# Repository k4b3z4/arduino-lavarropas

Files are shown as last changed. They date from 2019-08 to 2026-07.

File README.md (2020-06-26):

# arduino-lavarropas
 replacement of mechanical washing machine programmer with arduino uno

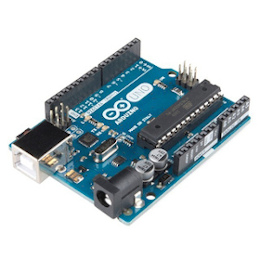
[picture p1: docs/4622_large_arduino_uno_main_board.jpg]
arduino

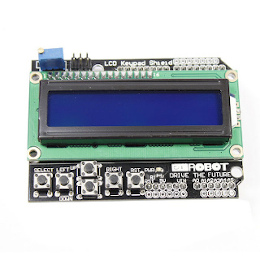
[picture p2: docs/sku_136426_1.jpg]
display shield

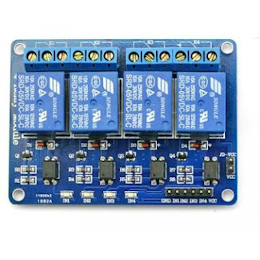
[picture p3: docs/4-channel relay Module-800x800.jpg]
relay module


# Esquema Electrico:

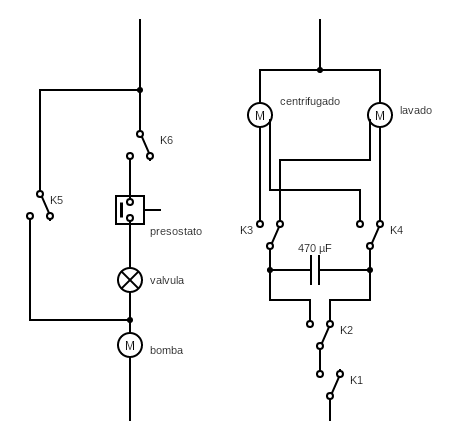
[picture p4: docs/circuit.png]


# Cableado Electrico:

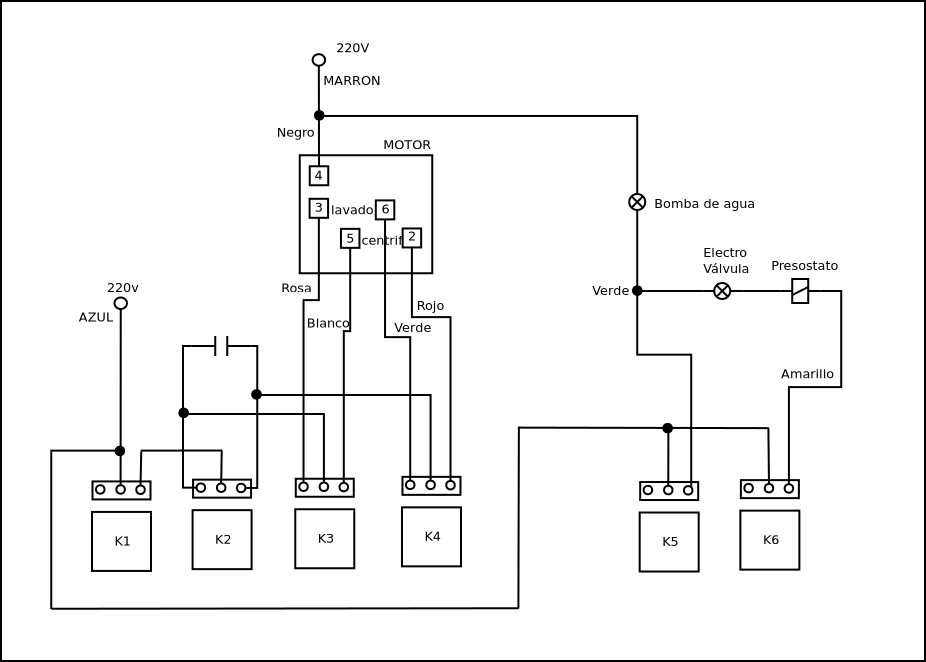
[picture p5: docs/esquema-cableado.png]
cableado


# Manual Orignal completo PDF

manual

# Funciona:

* Programa largo B -> C -> D -> E
* Programa corto K
* carga de agua
* bomba de vaciado 
* Presostato para limitar nivel de carga

# No Funciona:

* falta cableado bloqueador de apertura
* falta cableado calefactor y termostato
* falta selector de ingreso de agua, el sistema es mecánico (siempre está en posicion enjuague, no es un problema si se utiliza jabón liquido) 
* falta cableado boton "no centrifuga"
* falta cableado boton "no desagota"

# Archivos 3D:

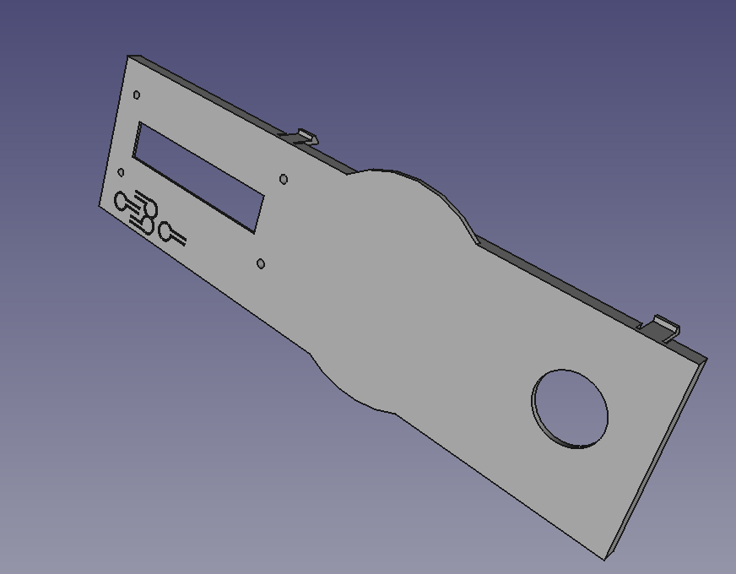
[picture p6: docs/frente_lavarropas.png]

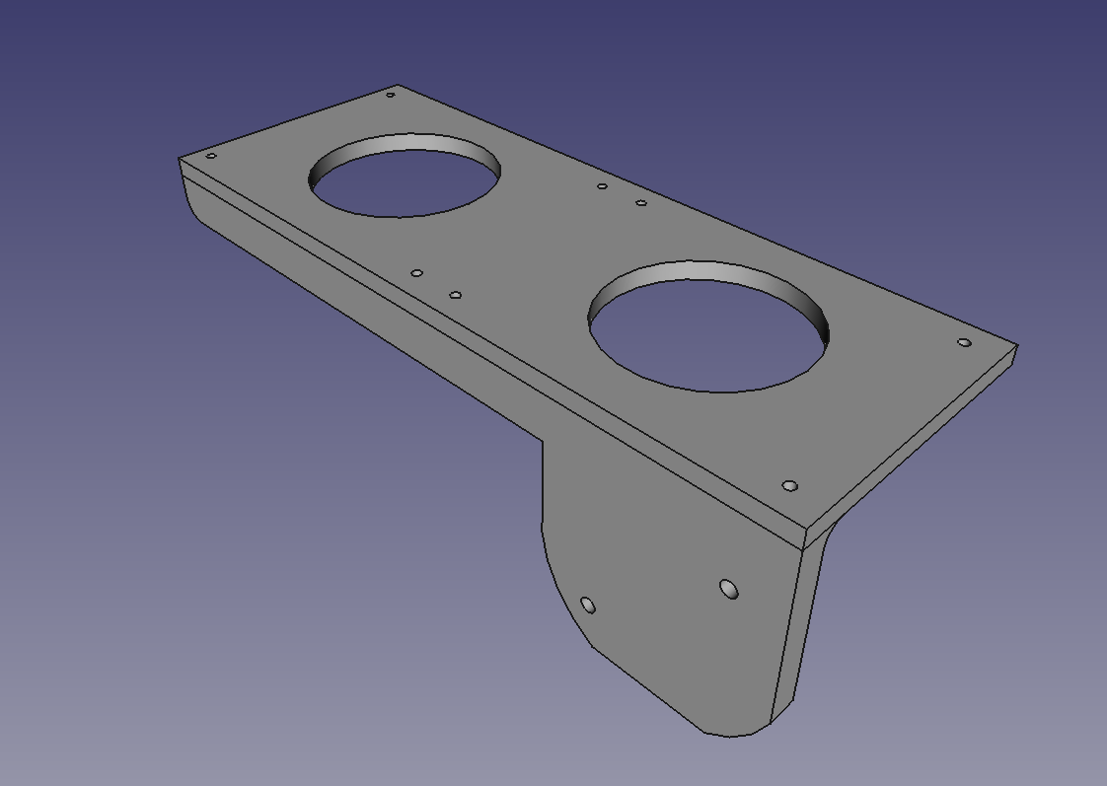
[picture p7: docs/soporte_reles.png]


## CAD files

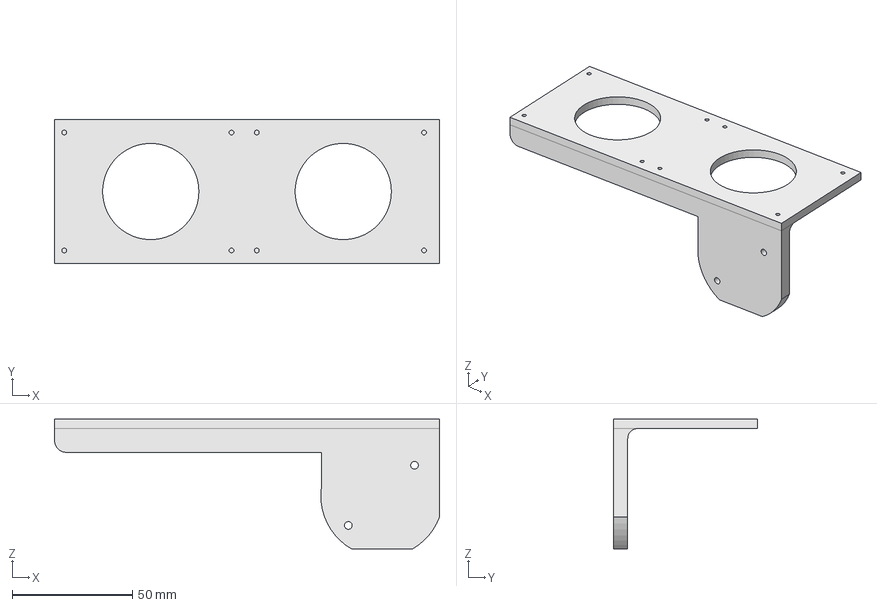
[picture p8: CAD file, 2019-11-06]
3D_files/soporte_lavarropas.FCStd
160.0 x 60.0 x 54.0 mm

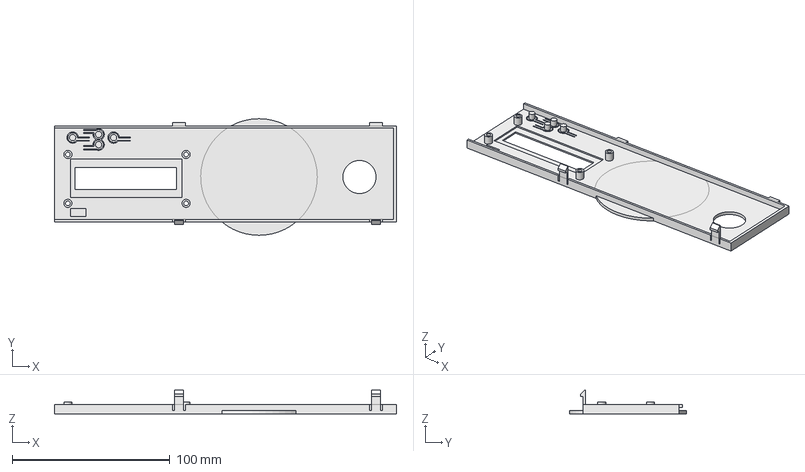
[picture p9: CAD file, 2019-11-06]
3D_files/frente_lavarropas.FCStd
217.0 x 74.0 x 15.0 mm

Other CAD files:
3D_files/frente_lavarropas.amf
3D_files/soporte_lavarropas.amf

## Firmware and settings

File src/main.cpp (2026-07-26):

// ********************************************************************
// Automatizacion Lavarropas
// Arduino Uno + LCD + encoder
// Federico Pedot fedped@gmail.com
//
// ********************************************************************

#include <Arduino.h>
#include <Wire.h>
#include <Timer.h>
#include <LiquidCrystal.h>
#include "programas.h"
#include <EEPROM.h>
#include "EEPROMAnything.h"



// ********************************************************************
// Config Shield

// LCD
#define PIN_RS A0
#define PIN_E  A1
#define PIN_D4 A2
#define PIN_D5 A3
#define PIN_D6 A4
#define PIN_D7 A5
#define PIN_CT 6

// DIGITAL
#define PIN_K1 8
#define PIN_K2 9
#define PIN_K3 10
#define PIN_K4 11
#define PIN_K5 12
#define PIN_K6 13


// ENCODER
#define PIN_CLK  2
#define PIN_DATA 3
#define PIN_SW   4

// BEEP
#define PIN_BEEP 7

// *******************************************************************

Timer timer2; // timer para Reloj
Timer timer3; // timer para beep

LiquidCrystal lcd(PIN_RS, PIN_E, PIN_D4, PIN_D5, PIN_D6, PIN_D7);


int    contador  = 0;
int    incrementa_contador = 0;
int    segundos  = 0;
bool   lavando   = false;
int    programa  = 1;
bool   cambia_programa = false;
int    boton     = 0;
char   buffer[18];

int  menu_posicion = 0;
int  menu_activar  = 0;
bool menu_presionado = false;
bool menu_parar = false;
bool menu_pausa = false;


int  encoder_val = 0;
int  encoder = 0;
int  state;


int beeps = 0;

// *******************************************************************

void IncrementaContador(void);
void Reloj(void);
void Beep(void);
void Estado(byte);
void doEncoder(void);
int  calculaTotal(int);

// *******************************************************************



void setup() {

    // contactores
    pinMode(PIN_K1, OUTPUT);
    pinMode(PIN_K2, OUTPUT);
    pinMode(PIN_K3, OUTPUT);
    pinMode(PIN_K4, OUTPUT);
    pinMode(PIN_K5, OUTPUT);
    pinMode(PIN_K6, OUTPUT);

    digitalWrite(PIN_K1, 1);
    digitalWrite(PIN_K2, 1);
    digitalWrite(PIN_K3, 1);
    digitalWrite(PIN_K4, 1);
    digitalWrite(PIN_K5, 1);
    digitalWrite(PIN_K6, 1);

    // encoder
    pinMode(PIN_SW, INPUT_PULLUP);
    pinMode(PIN_DATA, INPUT_PULLUP);
    pinMode(PIN_CLK, INPUT_PULLUP);
    
    // beep
    pinMode(PIN_BEEP, OUTPUT);
    digitalWrite(PIN_BEEP, 0);

    // contraste LCD
    pinMode(PIN_CT, OUTPUT);
    analogWrite(PIN_CT, 96);

    // 1 segundo
    timer2.every(1000, Reloj);

    // 200 ms
    timer3.every(200, Beep);

    // set up the LCD's number of columns and rows:
    lcd.begin(16, 2);

    // Primer programa
    cambia_programa = true;

    // segunda linea
    lcd.setCursor(0, 1);
    lcd.print("Listo...        ");


    // interrupcion encoder
    attachInterrupt(digitalPinToInterrupt(PIN_CLK), doEncoder, CHANGE);
    attachInterrupt(digitalPinToInterrupt(PIN_DATA), doEncoder, CHANGE);


    //recupera valores de la EEPROM
    EEPROM_readAnything(10, lavando);
    
    if(lavando){
        EEPROM_readAnything(20, programa);
        EEPROM_readAnything(30, segundos);
        EEPROM_readAnything(40, contador);
        cambia_programa = false;
        lcd.setCursor(0, 0);
        lcd.print("Recup");
        beeps = 2;
    }else{
        beeps = 3;
    }

}


// ###########################################################################
// ######################## Loop Principal ###################################

void loop() {

    // Menu seleccion de programa
    if (menu_posicion == 1 && lavando == false){

        lcd.setCursor(0,1);

        switch (encoder_val){
            case 1:
                lcd.print("[B]CDE-K-L-V-X-");
                break;
            case 2:
                lcd.print("B[C]DE-K-L-V-X-");
                break;
            case 3:
                lcd.print("BC[D]E-K-L-V-X-");
                break;
            case 4:
                lcd.print("BCD[E]-K-L-V-X-");
                break;
            case 5:
                lcd.print("BCDE[-]K-L-V-X-");
                break;
            case 6:
                lcd.print("BCDE-[K]-L-V-X-");
                break;
            case 7:
                lcd.print("BCDE-K[-]L-V-X-");
                break;
            case 8:
                lcd.print("BCDE-K-[L]-V-X-");
                break;
            case 9:
                lcd.print("BCDE-K-L[-]V-X-");
                break;
            case 10:
                lcd.print("BCDE-K-L-[V]-X-");
                break;
            case 11:
                lcd.print("BCDE-K-L-V[-]X-");
                break;
            case 12:
                lcd.print("BCDE-K-L-V-[X]-");
                break;
            case 13:
                lcd.print("BCDE-K-L-V-X[-]");
                break;
        }

        segundos = calculaTotal(encoder_val);

        if (encoder > 56) encoder = 56;
        if (encoder < 1)  encoder = 1; 
        

    }

    // Menu detener lavado (modo pausa)
    if( menu_posicion == 1 && lavando == true){

        if (encoder_val == 0){
            lcd.setCursor(0,1);       
            lcd.print("Parar? [No] Si ");
            menu_parar = false;
        }
        if (encoder_val == 1){ 
            lcd.setCursor(0,1);
            lcd.print("Parar?  No [Si]");
            menu_parar = true;
        }
        if (encoder > 7) encoder = 7;
        if (encoder < 0) encoder = 0;

    }


    // click Menu
    if( !digitalRead(PIN_SW) & !menu_presionado){

        menu_presionado = 1;
        encoder = 0;

        // activa menu principal
        if(menu_posicion == 0){
            encoder_val = 1;
            if (lavando == false){
                lcd.clear();
                lcd.setCursor(0,0);  
                lcd.print("Prg?");
                menu_posicion = 1;
            }else{
                menu_posicion = 1;
                menu_pausa = true;
                digitalWrite(PIN_K1, 1);
                digitalWrite(PIN_K2, 1);
                digitalWrite(PIN_K3, 1);
                digitalWrite(PIN_K4, 1);
                digitalWrite(PIN_K5, 1);
                digitalWrite(PIN_K6, 1);
            }
        }

        // vuelve del menu principal
        else if(menu_posicion == 1){
            if(lavando == false){ 
                // si no estaba lavando cambia al programa seleccionado
                // y comienza el ciclo de lavado 'lavando=true'
                programa = encoder_val;
                EEPROM_writeAnything(20, programa);
                lcd.setCursor(0,1);
                lcd.print("               ");
                if(programa == 1 || programa == 2 || 
                   programa == 3 || programa == 4 || 
                   programa == 6 || programa == 8 ||
                   programa == 10 || programa == 12 ){
                    lavando = true;
                    EEPROM_writeAnything(10, lavando);
                }
                cambia_programa = true;
            }else{
                // si estaba lavando y decido parar => lavando=false
                // si no quiero detener, todo sigue igual Continuando...
                if(menu_parar){
                    lavando = false;
                    EEPROM_writeAnything(10, lavando);
                    lcd.setCursor(0, 0);
                    lcd.print("Prog -  00:00:00");
                    lcd.setCursor(0, 1);
                    lcd.print("Finalizado      ");
                }else{
                    lcd.setCursor(0,1);
                    lcd.print("Continuando...  ");
                }
                menu_pausa = false;
            }
            menu_posicion = 0;
        }

    }

    if(digitalRead(PIN_SW)){
        menu_presionado = 0;
    }

    if(cambia_programa){

        lcd.setCursor(0, 0);

        switch (programa){
            case 1:
                lcd.print("Prg B");
                break;
            case 2:
                lcd.print("Prg C");
                break;
            case 3:
                lcd.print("Prg D");
                break;
            case 4:
                lcd.print("Prg E");
                break;
            case 6:
                lcd.print("Prg K");
                break;
            case 8:
                lcd.print("Prg L");
                break;
            case 10:
                lcd.print("Prg V");
                break;
            case 12:
                lcd.print("Prg X");
                break;
            case 5:
            case 7:
            case 9:
            case 11:
            case 13:
                lcd.print("Prg -");
                digitalWrite(PIN_K1, 1);
                digitalWrite(PIN_K2, 1);
                digitalWrite(PIN_K3, 1);
                digitalWrite(PIN_K4, 1);
                digitalWrite(PIN_K5, 1);
                digitalWrite(PIN_K6, 1);
                lavando = false;
                EEPROM_writeAnything(10, lavando);
                break;
        }

        segundos = calculaTotal(programa);
        cambia_programa = false;

    }

    timer2.update();
    timer3.update();

}

// ###########################################################################
// ###########################################################################


void Reloj(){

    int h;
    int m;
    int s;


    if(lavando == true and menu_pausa == false){
        segundos--;
        incrementa_contador++;
        if(incrementa_contador > 9){
            incrementa_contador = 0;
            IncrementaContador();
            EEPROM_writeAnything(30, segundos);
        }
    }


    h = segundos / 3600;
    m = ( segundos % 3600 ) / 60;
    s = ( segundos % 3600 ) % 60;

    lcd.setCursor(8, 0);
    sprintf(buffer,"%02d:%02d:%02d",h,m,s);
    lcd.print(buffer);


    return;
}

void Beep(void){

    if (beeps > 0){
        if(digitalRead(PIN_BEEP)){
            digitalWrite(PIN_BEEP,0);
            beeps--;
        }else{
            digitalWrite(PIN_BEEP,1);
        }
    }


}

// ###########################################################################
// ###########################################################################

void IncrementaContador() {

    if(programa == 1){
        digitalWrite(PIN_K1, !(PROG_B[contador] & B10000000 ));
        digitalWrite(PIN_K2, !(PROG_B[contador] & B01000000 ));
        digitalWrite(PIN_K3, !(PROG_B[contador] & B00100000 ));
        digitalWrite(PIN_K4, !(PROG_B[contador] & B00010000 ));
        digitalWrite(PIN_K5, !(PROG_B[contador] & B00001000 ));
        digitalWrite(PIN_K6, !(PROG_B[contador] & B00000100 ));
        if(PROG_B[contador] & B00000001) beeps = 6;
        Estado(PROG_B[contador]);
        if(contador == sizeof(PROG_B)-1 ){
            cambia_programa=true;
            programa ++;
            contador = 0;
            incrementa_contador = 0;
            EEPROM_writeAnything(20, programa);
            EEPROM_writeAnything(40, contador);
            return;
        }
    }

    if(programa == 2){
        digitalWrite(PIN_K1, !(PROG_C[contador] & B10000000 ));
        digitalWrite(PIN_K2, !(PROG_C[contador] & B01000000 ));
        digitalWrite(PIN_K3, !(PROG_C[contador] & B00100000 ));
        digitalWrite(PIN_K4, !(PROG_C[contador] & B00010000 ));
        digitalWrite(PIN_K5, !(PROG_C[contador] & B00001000 ));
        digitalWrite(PIN_K6, !(PROG_C[contador] & B00000100 ));
        if(PROG_C[contador] & B00000001) beeps = 6;
        Estado(PROG_C[contador]);
        if(contador == sizeof(PROG_C)-1 ){
            cambia_programa=true;
            programa ++;
            contador = 0;
            incrementa_contador = 0;
            EEPROM_writeAnything(20, programa);
            EEPROM_writeAnything(40, contador);
            return;
        }
    }

    if(programa == 3){
        digitalWrite(PIN_K1, !(PROG_D[contador] & B10000000));
        digitalWrite(PIN_K2, !(PROG_D[contador] & B01000000));
        digitalWrite(PIN_K3, !(PROG_D[contador] & B00100000));
        digitalWrite(PIN_K4, !(PROG_D[contador] & B00010000));
        digitalWrite(PIN_K5, !(PROG_D[contador] & B00001000));
        digitalWrite(PIN_K6, !(PROG_D[contador] & B00000100));
        if(PROG_D[contador] & B00000001) beeps = 6;
        Estado(PROG_D[contador]);
        if(contador == sizeof(PROG_D)-1 ){
            cambia_programa=true;
            programa ++;
            contador = 0;
            incrementa_contador = 0;
            EEPROM_writeAnything(20, programa);
            EEPROM_writeAnything(40, contador);
            return;
        }
    }

    if(programa == 4){
        digitalWrite(PIN_K1, !(PROG_E[contador] & B10000000));
        digitalWrite(PIN_K2, !(PROG_E[contador] & B01000000));
        digitalWrite(PIN_K3, !(PROG_E[contador] & B00100000));
        digitalWrite(PIN_K4, !(PROG_E[contador] & B00010000));
        digitalWrite(PIN_K5, !(PROG_E[contador] & B00001000));
        digitalWrite(PIN_K6, !(PROG_E[contador] & B00000100));
        if(PROG_E[contador] & B00000001) beeps = 6;
        Estado(PROG_E[contador]);
        if(contador == sizeof(PROG_E)-1 ){
            lcd.setCursor(0, 1);
            lcd.print("Finalizado      ");
            cambia_programa=true;
            programa ++;
            contador = 0;
            incrementa_contador = 0;
            EEPROM_writeAnything(20, programa);
            EEPROM_writeAnything(40, contador);
            return;
        }
    }

    if(programa == 6){
        digitalWrite(PIN_K1, !(PROG_K[contador] & B10000000));
        digitalWrite(PIN_K2, !(PROG_K[contador] & B01000000));
        digitalWrite(PIN_K3, !(PROG_K[contador] & B00100000));
        digitalWrite(PIN_K4, !(PROG_K[contador] & B00010000));
        digitalWrite(PIN_K5, !(PROG_K[contador] & B00001000));
        digitalWrite(PIN_K6, !(PROG_K[contador] & B00000100));
        if(PROG_K[contador] & B00000001) beeps = 6;
        Estado(PROG_K[contador]);
        if(contador == sizeof(PROG_K)-1 ){
            lcd.setCursor(0, 1);
            lcd.print("Finalizado      ");
            cambia_programa=true;
            programa ++;
            contador = 0;
            incrementa_contador = 0;
            EEPROM_writeAnything(20, programa);
            EEPROM_writeAnything(40, contador);
            return;
        }
    }

    if(programa == 8){
        digitalWrite(PIN_K1, !(PROG_L[contador] & B10000000));
        digitalWrite(PIN_K2, !(PROG_L[contador] & B01000000));
        digitalWrite(PIN_K3, !(PROG_L[contador] & B00100000));
        digitalWrite(PIN_K4, !(PROG_L[contador] & B00010000));
        digitalWrite(PIN_K5, !(PROG_L[contador] & B00001000));
        digitalWrite(PIN_K6, !(PROG_L[contador] & B00000100));
        if(PROG_L[contador] & B00000001) beeps = 6;
        Estado(PROG_L[contador]);
        if(contador == sizeof(PROG_L)-1 ){
            lcd.setCursor(0, 1);
            lcd.print("Finalizado      ");
            cambia_programa=true;
            programa ++;
            contador = 0;
            incrementa_contador = 0;
            EEPROM_writeAnything(20, programa);
            EEPROM_writeAnything(40, contador);
            return;
        }
    }

    if(programa == 10){
        digitalWrite(PIN_K1, !(PROG_V[contador] & B10000000));
        digitalWrite(PIN_K2, !(PROG_V[contador] & B01000000));
        digitalWrite(PIN_K3, !(PROG_V[contador] & B00100000));
        digitalWrite(PIN_K4, !(PROG_V[contador] & B00010000));
        digitalWrite(PIN_K5, !(PROG_V[contador] & B00001000));
        digitalWrite(PIN_K6, !(PROG_V[contador] & B00000100));
        if(PROG_V[contador] & B00000001) beeps = 6;
        Estado(PROG_V[contador]);
        if(contador == sizeof(PROG_V)-1 ){
            lcd.setCursor(0, 1);
            lcd.print("Finalizado      ");
            cambia_programa=true;
            programa ++;
            contador = 0;
            incrementa_contador = 0;
            EEPROM_writeAnything(20, programa);
            EEPROM_writeAnything(40, contador);
            return;
        }
    }

    if(programa == 12){
        digitalWrite(PIN_K1, !(PROG_X[contador] & B10000000));
        digitalWrite(PIN_K2, !(PROG_X[contador] & B01000000));
        digitalWrite(PIN_K3, !(PROG_X[contador] & B00100000));
        digitalWrite(PIN_K4, !(PROG_X[contador] & B00010000));
        digitalWrite(PIN_K5, !(PROG_X[contador] & B00001000));
        digitalWrite(PIN_K6, !(PROG_X[contador] & B00000100));
        if(PROG_X[contador] & B00000001) beeps = 6;
        Estado(PROG_X[contador]);
        if(contador == sizeof(PROG_X)-1 ){
            lcd.setCursor(0, 1);
            lcd.print("Finalizado      ");
            cambia_programa=true;
            programa ++;
            contador = 0;
            incrementa_contador = 0;
            EEPROM_writeAnything(20, programa);
            EEPROM_writeAnything(40, contador);
            return;
        }
    }

    contador ++;
    EEPROM_writeAnything(40, contador);

}


// ###########################################################################
// ###########################################################################


void Estado(byte B){

    if(menu_posicion == 0){
        lcd.setCursor(0, 1);
        
        if(B & B00100000){
            lcd.print("Centrifugando...");
            return;
        }
        if(B & B10000000){
            if(B & B01000000){
                lcd.print("Lavando... [<-] ");
            }else{
                lcd.print("Lavando... [->] ");
            }
            return;
        }
        if(B & B00000100){
            lcd.print("Llenando...     ");
            return;
        }
        if(B & B00001000){
            lcd.print("Vaciando...     ");
            return;
        }
        lcd.print("Esperando...    ");
        return;

    }
   
}

int calculaTotal(int prog){

    int seg = 0;

    switch (prog){
        case 1:
            seg += sizeof(PROG_B)*10;
        case 2:
            seg += sizeof(PROG_C)*10;
        case 3:
            seg += sizeof(PROG_D)*10;
        case 4:
            seg += sizeof(PROG_E)*10;
            break;
        case 6:
            seg += sizeof(PROG_K)*10;
            break;
        case 8:
            seg += sizeof(PROG_L)*10;
            break;
        case 10:
            seg += sizeof(PROG_V)*10;
            break;
        case 12:
            seg += sizeof(PROG_X)*10;
            break;
    }

    return seg;

}


void doEncoder(){

    //                           _______         _______       
    //               Pin1 ______|       |_______|       |______ Pin1
    // negative <---         _______         _______         __      --> positive
    //               Pin2 __|       |_______|       |_______|   Pin2

    //	    new	            old
    //	pin2	pin1	pin2	pin1	Result
    //	----	----	----	----	------
    //	0	    0	    0  	    0	    no movement
    //	0	    0	    0  	    1	    +1
    //	0	    0	    1	    0	    -1
    //	0	    0	    1	    1	    +2  (assume pin1 edges only)
    //	0	    1	    0	    0	    -1
    //	0	    1	    0	    1	    no movement
    //	0	    1	    1	    0	    -2  (assume pin1 edges only)
    //	0	    1	    1	    1	    +1
    //	1	    0	    0	    0	    +1
    //	1	    0	    0	    1	    -2  (assume pin1 edges only)
    //	1	    0	    1	    0	    no movement
    //	1	    0	    1	    1	    -1
    //	1	    1	    0	    0	    +2  (assume pin1 edges only)
    //	1	    1	    0	    1	    -1
    //	1	    1	    1	    0	    +1
    //	1	    1	    1	    1	    no movement



    uint8_t s = state & 3;

    if (digitalRead(PIN_CLK))  s |= 4;
    if (digitalRead(PIN_DATA)) s |= 8;

    switch (s) {
        case 0: case 5: case 10: case 15:
            break;
        case 1: case 7: case 8: case 14:
            encoder++; break;
        case 2: case 4: case 11: case 13:
            encoder--; break;
        case 3: case 12:
            encoder += 2; break;
        default:
            encoder -= 2; break;
    }
    encoder_val = encoder / 4;
    state = (s >> 2);


}

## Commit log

2019-08-13 archivo separado para definicion de programas de lavado
2019-11-06 agregado archivos 3D
    [frente_lavarropas.FCStd, frente_lavarropas.amf, soporte_lavarropas.FCStd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]
2019-11-06 Fix, leyendas programa finalizado
    [main.cpp]
2020-01-02 agregado esquema de cableado
2022-09-11 encoder version
2022-09-11 switch mejorado
2024-12-30 fix encoder, nuevos programas
    [main.cpp]
2026-02-03 recupera cortes de luz
2026-06-22 cambio pines encoder
2026-06-23 implementacion de encoder.h
2026-07-12 activo/desactivo k2 antes que k1
2026-07-13 arreglo bug continuar en menu pausa
    [main.cpp]
2026-07-26 unificacion Timer1 y Timer2
2026-07-26 fix vuelta del menu parar
    [main.cpp]
2026-07-26 cambio orden de mensajes
2026-07-26 reset incrementa_contador cuando inicia cada programa
    [main.cpp]
